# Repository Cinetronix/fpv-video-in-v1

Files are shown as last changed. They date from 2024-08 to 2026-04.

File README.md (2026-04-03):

# Cinetronix FPV Video Input Board v1

KiCad hardware design for an HDMI-to-MIPI CSI bridge board, designed for FPV camera systems.

## Overview

Converts HDMI video input to MIPI CSI-2 output using the Toshiba TC9590XBG bridge IC, controlled by an ESP32-S3 microcontroller.

### Key Components

| Component | Function |
|---|---|
| TC9590XBG | HDMI to MIPI CSI-2 bridge |
| ESP32-S3 | Control MCU |
| TS5MP645YFPR | HDMI multiplexer |
| TPD8S009DSMR | HDMI ESD protection |
| TPD6E05U06RVZR | Additional ESD protection |
| DF56C-26S | Micro-coax connector (CSI output) |

## Board Designs

- **TC9590XBG-PCB/** — Main board with HDMI input, CSI output, and ESP32-S3 control
- **DF56C-26S-breakout-board-PCB/** — Breakout board for the 26-pin DF56C micro-coax connector
- **DF56C-30S-breakout-board-PCB/** — Breakout board for the 30-pin DF56C micro-coax connector

## Requirements

- [KiCad](https://www.kicad.org/) 7+
- [KiKit](https://github.com/yaqwsx/KiKit) (for panel generation)

## Panelization

Generate a manufacturing panel from the `TC9590XBG-PCB/` directory:

```bash
kikit panelize \
    --layout "grid; rows: 1; cols: 3; space: 5mm;" \
    --tabs "fixed; width: 5mm;" \
    --cuts "mousebites; drill: 0.5mm; spacing: 1mm; offset: 0.2mm; prolong: 0.5mm" \
    --framing "railstb; width: 5mm; space: 3mm; mintotalheight: 72mm; mintotalwidth: 72mm" \
    --tooling "3hole; hoffset: 2.5mm; voffset: 2.5mm; size: 1.5mm" \
    --fiducials "3fid; hoffset: 5mm; voffset: 2.5mm; coppersize: 2mm; opening: 1mm;" \
    --text "simple; text: Cinetronix Video input v1.1a; anchor: mt; voffset: 2.5mm; hjustify: center; vjustify: center;" \
    --post "millradius: 1mm" \
    fpv-video-in-v1.kicad_pcb Panel/panel.kicad_pcb
```

## Project Structure

Each board subdirectory contains its own KiCad project files (`.kicad_pro`, `.kicad_sch`, `.kicad_pcb`) along with a `lib/` directory for custom symbols, footprints, and 3D models.

## License

Copyright Cinetronix. All rights reserved.

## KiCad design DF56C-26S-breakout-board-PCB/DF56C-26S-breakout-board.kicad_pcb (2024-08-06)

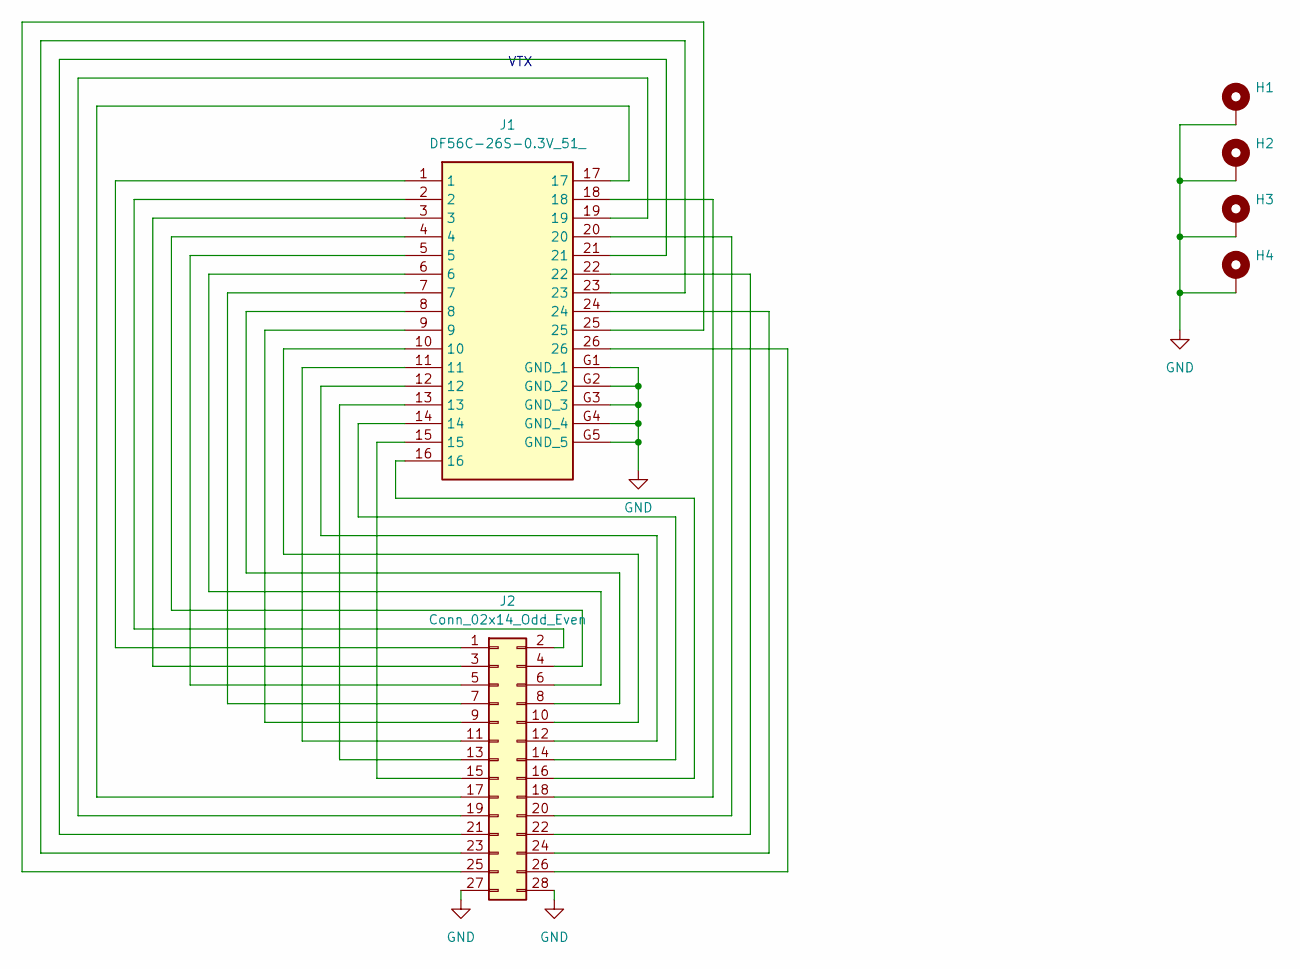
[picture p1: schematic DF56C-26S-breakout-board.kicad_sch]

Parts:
H1, H2, H3, H4: MountingHole_Pad; MountingHole_2.2mm_M2_Pad_Via
J1: DF56C-26S-0.3V_51_; DF56C26S03V51; Mouser Part Number 798-DF56C-26S-0.3V51
J2: Conn_02x14_Odd_Even; PinHeader_2x14_P2.54mm_Vertical

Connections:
GND: H1.1, H2.1, H3.1, H4.1, J1.G1 (GND_1), J1.G2 (GND_2), J1.G3 (GND_3), J1.G4 (GND_4), J1.G5 (GND_5), J2.27, J2.28
unnamed: J1.1, J2.1
unnamed: J1.2, J2.2
unnamed: J1.3, J2.3
unnamed: J1.4, J2.4
unnamed: J1.5, J2.5
unnamed: J1.6, J2.6
unnamed: J1.7, J2.7
unnamed: J1.8, J2.8
unnamed: J1.9, J2.9
unnamed: J1.10, J2.10
unnamed: J1.11, J2.11
unnamed: J1.12, J2.12
unnamed: J1.13, J2.13
unnamed: J1.14, J2.14
unnamed: J1.15, J2.15
unnamed: J1.16, J2.16
unnamed: J1.17, J2.17
unnamed: J1.18, J2.18
unnamed: J1.19, J2.19
unnamed: J1.20, J2.20
unnamed: J1.21, J2.21
unnamed: J1.22, J2.22
unnamed: J1.23, J2.23
unnamed: J1.24, J2.24
unnamed: J1.25, J2.25
unnamed: J1.26, J2.26

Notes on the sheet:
VTX

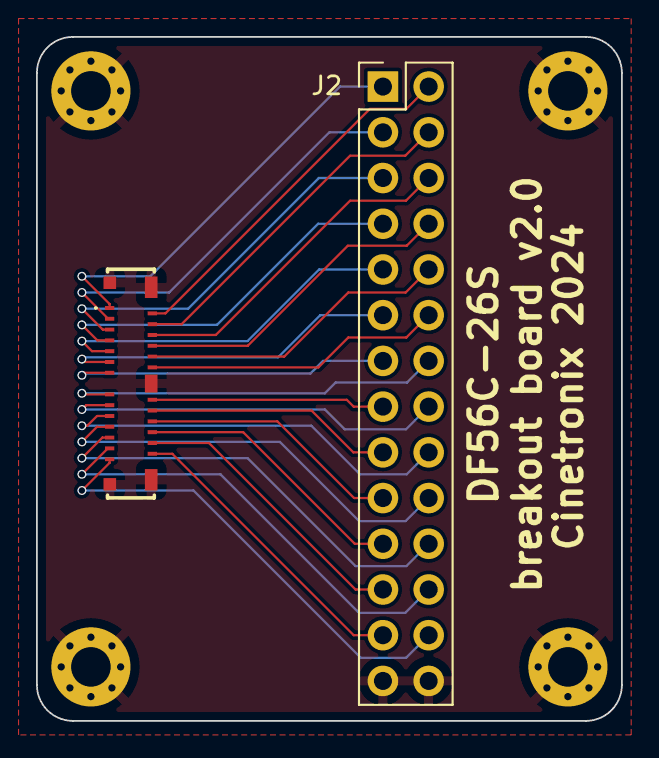
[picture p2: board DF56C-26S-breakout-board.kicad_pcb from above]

Board: 2 copper layers, 32.5 x 38.0 mm, 6 parts (0 on the bottom side), 27 nets.

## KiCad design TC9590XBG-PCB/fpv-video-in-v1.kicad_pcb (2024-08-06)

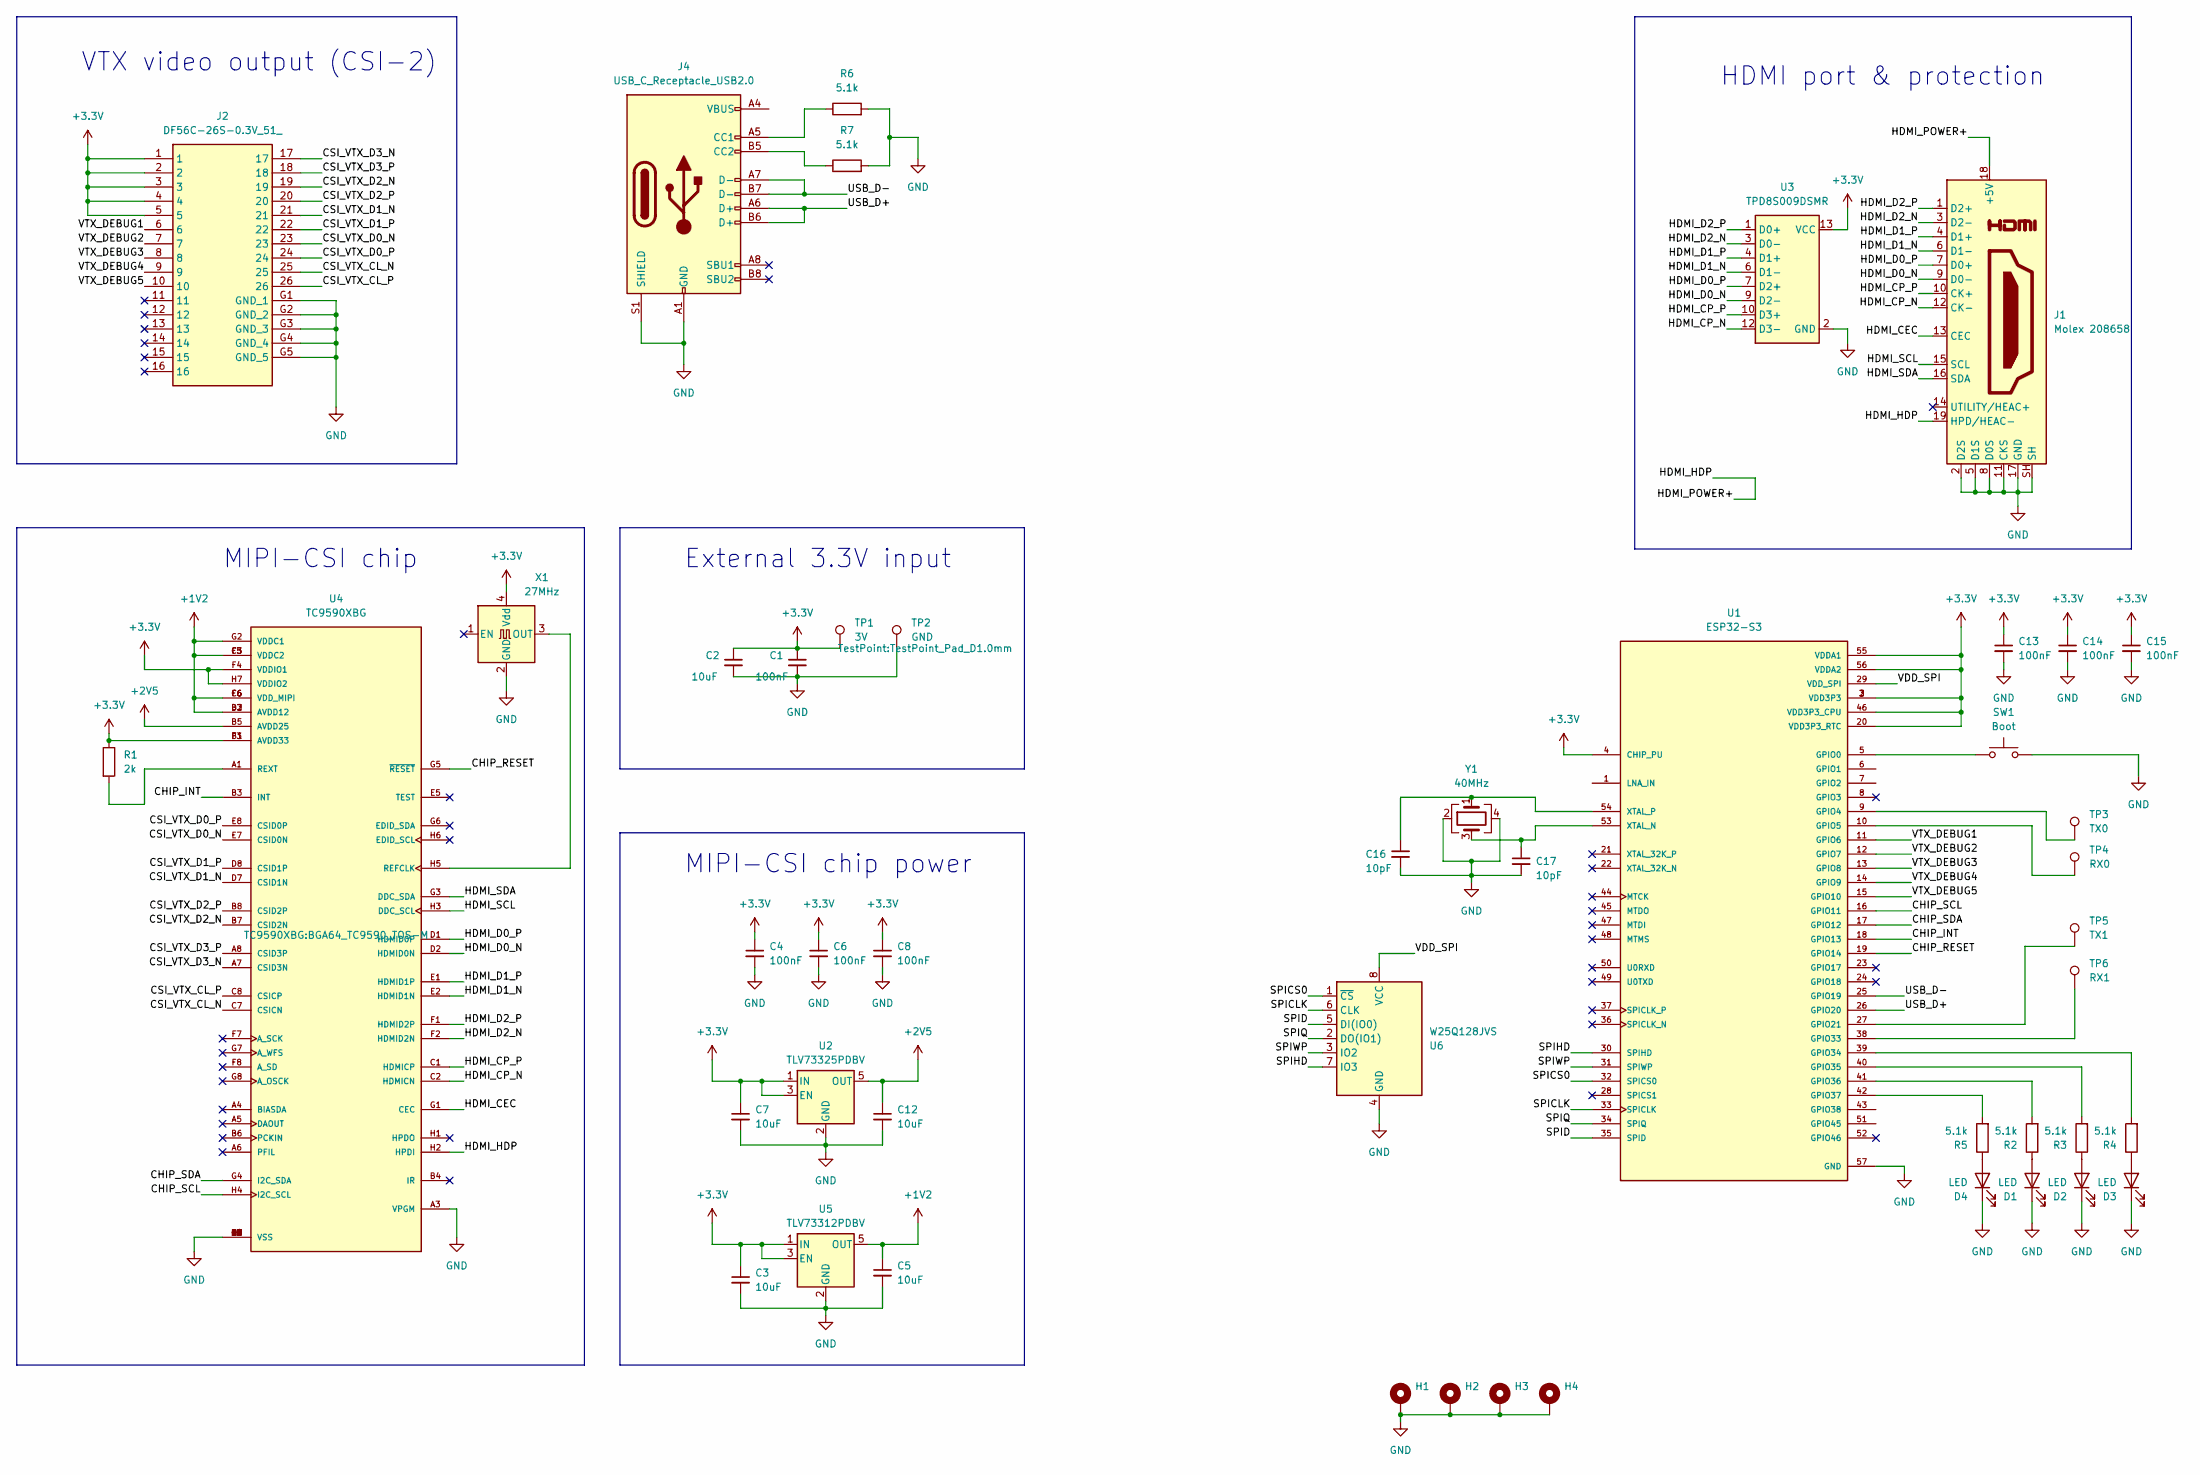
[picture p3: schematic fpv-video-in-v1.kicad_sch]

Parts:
C1, C4, C6, C8, C13, C14, C15: 100nF; C_0402_1005Metric
C2, C3, C5, C7, C12: 10uF; C_0402_1005Metric
C16, C17: 10pF; C_0402_1005Metric
D1, D2, D3, D4: LED; LED_0603_1608Metric
H1, H2, H3, H4: MountingHole_Pad; MountingHole_2.2mm_M2_Pad
J1: Molex 208658; HDMI_A_Molex_208658-1001_Horizontal
J2: DF56C-26S-0.3V_51_; DF56C26S03V51; Mouser Part Number 798-DF56C-26S-0.3V51
J4: USB_C_Receptacle_USB2.0; USB_C_Receptacle_G-Switch_GT-USB-7010ASV
R1: 2k; R_0402_1005Metric
R2, R3, R4, R5, R6, R7: 5.1k; R_0402_1005Metric
SW1: Boot; SW_Push_SPST_NO_Alps_SKRK; LCSC C115357
TP1: 3V; TestPoint_Pad_D1.0mm
TP2: GND; TestPoint_Pad_D1.0mm
TP3: TX0; TestPoint_Pad_D1.5mm
TP4: RX0; TestPoint_Pad_D1.5mm
TP5: TX1; TestPoint_Pad_D1.0mm
TP6: RX1; TestPoint_Pad_D1.0mm
U1: ESP32-S3; QFN40P700X700X90-57N-D; PARTREV v1.2
U2: TLV73325PDBV; SOT-23-5
U3: TPD8S009DSMR; R-PDSO-N15; MPN TPD8S009DSMR
U4: TC9590XBG; BGA64_TC9590_TOS-M; PARTREV 1.4
U5: TLV73312PDBV; SOT-23-5
U6: W25Q128JVS; WSON-8-1EP_6x5mm_P1.27mm_EP3.4x4.3mm
X1: 27MHz; Crystal_SMD_2016-4Pin_2.0x1.6mm
Y1: 40MHz; Crystal_SMD_2016-4Pin_2.0x1.6mm

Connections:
+1V2: C5.1, U4.B2 (AVDD12), U4.C3 (VDDC2), U4.C6 (VDD_MIPI), U4.D3 (AVDD12), U4.F5 (VDDC2), U4.F6 (VDD_MIPI), U4.G2 (VDDC1), U5.5 (OUT)
+2V5: C12.1, U2.5 (OUT), U4.B5 (AVDD25)
+3.3V: C1.1, C2.1, C3.1, C4.1, C6.1, C7.1, C8.1, C13.1, C14.1, C15.1, J2.1, J2.2, J2.3, J2.4, J2.5, R1.1, TP1.1, U1.2 (VDD3P3), U1.3 (VDD3P3), U1.4 (CHIP_PU), U1.20 (VDD3P3_RTC), U1.46 (VDD3P3_CPU), U1.55 (VDDA1), U1.56 (VDDA2), U2.1 (IN), U2.3 (EN), U3.13 (VCC), U3.15 (VCC), U4.B1 (AVDD33), U4.F3 (AVDD33), U4.F4 (VDDIO1), U4.H7 (VDDIO2), U5.1 (IN), U5.3 (EN), X1.4 (Vdd)
/CHIP_INT: U1.18 (GPIO13), U4.B3 (INT)
/CHIP_RESET: U1.19 (GPIO14), U4.G5 (~RESET)
/CHIP_SCL: U1.16 (GPIO11), U4.H4 (I2C_SCL)
/CHIP_SDA: U1.17 (GPIO12), U4.G4 (I2C_SDA)
/CSI_VTX_CL_N: J2.25, U4.C7 (CSICN)
/CSI_VTX_CL_P: J2.26, U4.C8 (CSICP)
/CSI_VTX_D0_N: J2.23, U4.E7 (CSID0N)
/CSI_VTX_D0_P: J2.24, U4.E8 (CSID0P)
/CSI_VTX_D1_N: J2.21, U4.D7 (CSID1N)
/CSI_VTX_D1_P: J2.22, U4.D8 (CSID1P)
/CSI_VTX_D2_N: J2.19, U4.B7 (CSID2N)
/CSI_VTX_D2_P: J2.20, U4.B8 (CSID2P)
/CSI_VTX_D3_N: J2.17, U4.A7 (CSID3N)
/CSI_VTX_D3_P: J2.18, U4.A8 (CSID3P)
/HDMI_CEC: J1.13 (CEC), U4.G1 (CEC)
/HDMI_CP_N: J1.12 (CK-), U3.12 (D3-), U4.C2 (HDMICN)
/HDMI_CP_P: J1.10 (CK+), U3.10 (D3+), U4.C1 (HDMICP)
/HDMI_D0_N: J1.9 (D0-), U3.9 (D2-), U4.D2 (HDMID0N)
/HDMI_D0_P: J1.7 (D0+), U3.7 (D2+), U4.D1 (HDMID0P)
/HDMI_D1_N: J1.6 (D1-), U3.6 (D1-), U4.E2 (HDMID1N)
/HDMI_D1_P: J1.4 (D1+), U3.4 (D1+), U4.E1 (HDMID1P)
/HDMI_D2_N: J1.3 (D2-), U3.3 (D0-), U4.F2 (HDMID2N)
/HDMI_D2_P: J1.1 (D2+), U3.1 (D0+), U4.F1 (HDMID2P)
/HDMI_HDP: J1.18 (+5V), J1.19 (HPD/HEAC-), U4.H2 (HPDI)
/HDMI_SCL: J1.15 (SCL), U4.H3 (DDC_SCL)
/HDMI_SDA: J1.16 (SDA), U4.G3 (DDC_SDA)
/SPICLK: U1.33 (SPICLK), U6.6 (CLK)
/SPICS0: U1.32 (SPICS0), U6.1 (~CS)
/SPID: U1.35 (SPID), U6.5 (DI(IO0))
/SPIHD: U1.30 (SPIHD), U6.7 (IO3)
/SPIQ: U1.34 (SPIQ), U6.2 (DO(IO1))
/SPIWP: U1.31 (SPIWP), U6.3 (IO2)
/USB_D+: J4.A6 (D+), J4.B6 (D+), U1.26 (GPIO20)
/USB_D-: J4.A7 (D-), J4.B7 (D-), U1.25 (GPIO19)
/VDD_SPI: U1.29 (VDD_SPI), U6.8 (VCC)
/VTX_DEBUG1: J2.6, U1.11 (GPIO6)
/VTX_DEBUG2: J2.7, U1.12 (GPIO7)
/VTX_DEBUG3: J2.8, U1.13 (GPIO8)
/VTX_DEBUG4: J2.9, U1.14 (GPIO9)
/VTX_DEBUG5: J2.10, U1.15 (GPIO10)
GND: C1.2, C2.2, C3.2, C4.2, C5.2, C6.2, C7.2, C8.2, C12.2, C13.2, C14.2, C15.2, C16.2, C17.2, D1.1 (K), D2.1 (K), D3.1 (K), D4.1 (K), H1.1, H2.1, H3.1, H4.1, J1.2 (D2S), J1.5 (D1S), J1.8 (D0S), J1.11 (CKS), J1.17 (GND), J1.SH, J2.G1 (GND_1), J2.G2 (GND_2), J2.G3 (GND_3), J2.G4 (GND_4), J2.G5 (GND_5), J4.A1 (GND), J4.A12 (GND), J4.B1 (GND), J4.B12 (GND), J4.S1 (SHIELD), R6.2, R7.2, SW1.2, TP2.1, U1.57 (GND), U2.2 (GND), U3.2 (GND), U3.5 (GND), U3.8 (GND), U3.11 (GND), U4.A2 (VSS), U4.A3 (VPGM), U4.C4 (VSS), U4.C5 (VSS), U4.D4 (VSS), U4.D5 (VSS), U4.D6 (VSS), U4.E3 (VSS), U4.E4 (VSS), U4.E6 (VSS), U4.H8 (VSS), U5.2 (GND), U6.4 (GND), X1.2 (GND), Y1.2, Y1.4
unnamed: D1.2 (A), R2.1
unnamed: D2.2 (A), R3.1
unnamed: D3.2 (A), R4.1
unnamed: D4.2 (A), R5.1
unnamed: J4.A5 (CC1), R6.1
unnamed: J4.B5 (CC2), R7.1
unnamed: J4.A4 (VBUS), J4.A9 (VBUS), J4.B4 (VBUS), J4.B9 (VBUS)
unnamed: SW1.1, U1.5 (GPIO0)
unnamed: TP3.1, U1.9 (GPIO4)
unnamed: TP4.1, U1.10 (GPIO5)
unnamed: TP5.1, U1.27 (GPIO21)
unnamed: TP6.1, U1.38 (GPIO33)
unnamed: R4.2, U1.39 (GPIO34)
unnamed: R3.2, U1.40 (GPIO35)
unnamed: R2.2, U1.41 (GPIO36)
unnamed: R5.2, U1.42 (GPIO37)
unnamed: C17.1, U1.53 (XTAL_N), Y1.3
unnamed: C16.1, U1.54 (XTAL_P), Y1.1
unnamed: U4.H5 (REFCLK), X1.3 (OUT)
unnamed: R1.2, U4.A1 (REXT)

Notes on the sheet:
HDMI port & protection
MIPI-CSI chip power
MIPI-CSI chip
VTX video output (CSI-2)
External 3.3V input

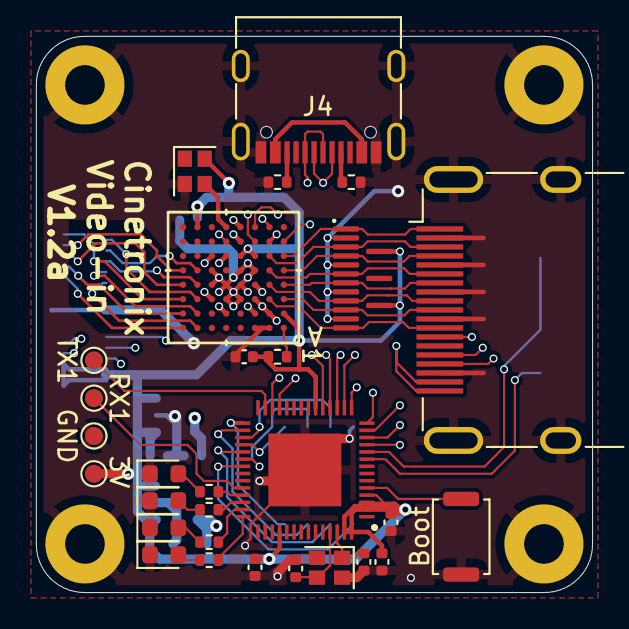
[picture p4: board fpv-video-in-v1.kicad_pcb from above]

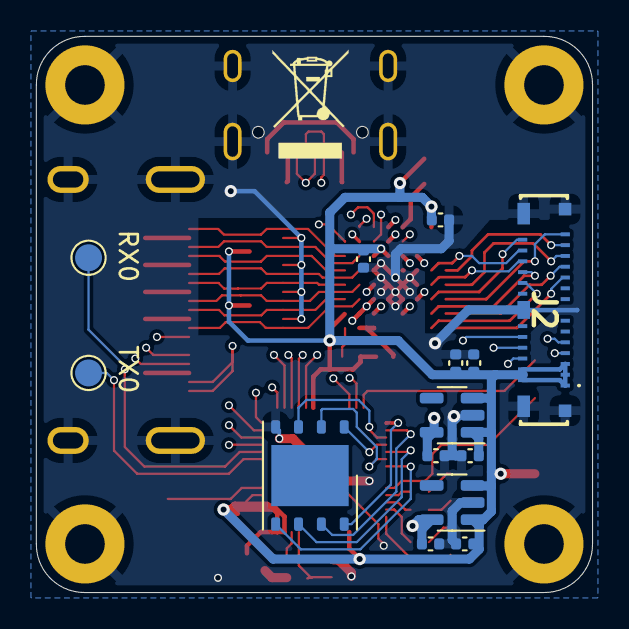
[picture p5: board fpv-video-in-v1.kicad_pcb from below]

Board: 4 copper layers, 30.9 x 30.9 mm, 47 parts (14 on the bottom side), 64 nets.

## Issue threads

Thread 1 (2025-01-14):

Request for ESP32 Firmware and TC9590XBG Output Signal Algorithm

AiKart, 2025-01-14:
Hi,

First of all, I'd like to thank you for creating and sharing the fpv-video-in-v1 project. It's a fantastic piece of work, and I'm very excited to try and replicate it, as well as attempt some modifications and upgrades.

I've noticed that the project provides the PCB engineering files for the hardware. However, it appears that the hardware requires the ESP32 chip's firmware and the algorithm to control the TC9590XBG output signal to function correctly. These items don't seem to be included in the repository.

Could you kindly share the ESP32 firmware and the algorithm for controlling the TC9590XBG output signal? It would be incredibly helpful for me and others looking to work with and build upon this project.

Thank you for your time and assistance!

Best regards, Kart.

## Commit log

2024-08-06 Add DF56C-30S dev board
    [fpv-hdmi.kicad_pcb, fpv-hdmi.kicad_sch]
2024-08-06 Add DF56C-26S dev board
    [fpv-hdmi.kicad_pcb, fpv-hdmi.kicad_sch]
2024-08-06 Add TC9590 implementation
    [fpv-hdmi-v2.kicad_pcb, fpv-hdmi-v2.kicad_sch]
2024-08-06 Rename boards
    [fpv-video-in-v1.kicad_pcb, fpv-video-in-v1.kicad_sch]
2026-04-03 Fix CI workflow and add Dependabot
    Use actions-for-kicad/kicad-actions instead of raw container to fix
    EACCES permission errors during checkout. Add Dependabot for weekly
    GitHub Actions updates.
2026-04-03 Split schematic PDF export into its own step
    The schematic PDF wasn't being generated when combined with run_erc
    in the same action invocation.
2026-04-03 Bump actions-for-kicad/kicad-actions from 1.6.pre.k9.0 to 9.0.4
    Bumps [actions-for-kicad/kicad-actions](https://github.com/actions-for-kicad/kicad-actions) from 1.6.pre.k9.0 to 9.0.4.
    - [Release notes](https://github.com/actions-for-kicad/kicad-actions/releases)
    - [Changelog](https://github.com/actions-for-kicad/kicad-actions/blob/main/release-procdure.md)
    - [Commits](https://github.com/actions-for-kicad/kicad-actions/compare/v1.6-k9.0...v1.6-k9.0.4)
    ---
    updated-dependencies:
    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

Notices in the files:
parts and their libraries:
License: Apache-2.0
